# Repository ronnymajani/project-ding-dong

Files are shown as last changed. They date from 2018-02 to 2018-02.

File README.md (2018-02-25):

# Project Ding Dong
An automated doorbell that messages you via a Telegram channel whenever someone rings your doorbell. Powered by the ESP8266
###### [Full Project Description at Hackaday.io](https://hackaday.io/project/61540-project-ding-dong)
------------------------

***The README is not yet complete***

### NOTE:
I omitted a file called `credentials.py` in which I store the TOKEN of my bot and the channel ID that it will push messages to.
So to be able to get the code running don't forget to create this file in the folder `code` and fill it as follows:
``` python
# credentials.py

# This is the generated access token for your telegram bot
TOKEN = ""
# This is the chat id of the channel your bot will push messages to
CHANNEL_ID = ""
# wireless credentials
WIFI_SSID = ""
WIFI_PASS = ""
```

Tools Used:
-------------
- **OpenSCAD** to edit the 3D models for the chassis
- **Telegram** to be able to communicate with the *doorbell*
- **Eagle** to be able to edit the electronic schematics
- **esptool** for flashing the ESP8266
- **mpfshell** for easily transfering files from the computer to the ESP8266

Repository layout:
----------
- **chassis:** this folder contains the OpenSCAD files for the chassis that encompasses the entire system
- **code:** this folder contains the code that will run on the ESP8266
- **schematics:** this folder contains the electronic schematics files that are used to make the PCB board

Third Party Resources and Useful Links:
----------------------
- [Micropython for the ESP8266 Read the Docs page](https://docs.micropython.org/en/latest/esp8266/index.html)
- [urequests.py micropython module](https://github.com/micropython/micropython-lib/blob/master/urequests/urequests.py)
- [Telegram Bots API](https://core.telegram.org/bots/api)
- [mpfshell github page](https://github.com/wendlers/mpfshell)
- [Nice article explaining how to hook up a LiPo battery to the ESP8266](https://randomnerdtutorials.com/esp8266-voltage-regulator-lipo-and-li-ion-batteries/)
- [EagleCAD Library for most/all ESP8266 variants](https://github.com/wvanvlaenderen/ESP8266-Eagle_Library)
- [OpenSCAD Socket Design for the ESP8266-07](https://github.com/makertum/ESP8266-RNS)
- [How to get the your telegram channel's id](https://github.com/GabrielRF/telegram-id#web-channel-id)
- [Eagle CAD library for Microchip components](https://www.element14.com/community/docs/DOC-64255/l/microchip-cad-library-for-cadsoft-eagle-software)
- [Eagle CAD library for basic parts by itead.cc (*like the BC557 PNP BJT*)](https://www.itead.cc/blog/eagle-library-for-basic-parts-series)

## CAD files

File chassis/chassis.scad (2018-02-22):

/**
@title: Project Ding Dong encasing
@author: Ronny Majani
**/
/* Module Definitions */
/*
Creates a block in the dimensions of the chassis
This module uses the globally defined width, height, and depth variables
*/
module chassis_fill(width, height, depth) {
    dimensions = [
        width,
        depth,
        height
    ];
    cube(dimensions);
}

/*
Creates the chassis' hull which is a an outer shell with empty space inside
@param thickness: the thickness of the chassis' inner walls
@param depth: the depth of the inner space
*/
module chassis_hull(width, height, outer_depth, inner_depth, thickness) {
    offset_fix = 0.1;
    inner_dimensions = [
        width - thickness*2,
        inner_depth + offset_fix,
        height - thickness*2
    ];
    difference() {
        chassis_fill(width, height, outer_depth);
        translate([thickness, -offset_fix, thickness]) {
            resize(inner_dimensions) chassis_fill();
        }
    }
}



/* Generate Chassis */
chassis_outer_width = 30;
chassis_outer_height = 48;
chassis_outer_depth = 23;
chassis_inner_depth = 20;
chassis_thickness = 2;
chassis_hull(chassis_outer_width,
            chassis_outer_height,
            chassis_outer_depth,
            chassis_inner_depth,
            chassis_thickness);

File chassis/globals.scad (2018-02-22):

// units are in millimeters
chassis_outer_width = 30;
chassis_outer_height = 48;

chassis_outer_depth = 23;
chassis_inner_depth = 20;

chassis_thickness = 3;

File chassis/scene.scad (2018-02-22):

include <globals.scad>
use <chassis.scad>
use <ESP8266-07-RNS-v7.scad>

%translate([1.5, chassis_inner_depth-9, 10]) rotate([90, 0, 0]) {
    socket();
}
/** Main Scene **/
chassis_hull(chassis_outer_width,
            chassis_outer_height,
            chassis_outer_depth,
            chassis_inner_depth,
            chassis_thickness);;




/** Support Objects **/
/*
Used only as a guide to show how the chassis will be mounted
*/
module mount_grips() {
    width = 5;
    height = 11;
    inner_depth = chassis_outer_depth;
    top_thickness = 2;
    depth = inner_depth + top_thickness;
    side_thickness = 3;
    inner_width = width - side_thickness;

    mirror()translate([-inner_width, -top_thickness, 0]) {
        difference() {
            cube([width, depth, height]);  // outer cube
            translate([-0.2, top_thickness
    , -0.2]) {  // inner cube (cut out)
                cube([inner_width + 0.2, inner_depth+0.2, height + 0.4]);
            }
        }
    }
}

%translate([0, 0, 21]) {
    mount_grips();   

    mirror() translate([-chassis_outer_width, 0, 0]){
        mount_grips();
    }
}

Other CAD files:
chassis/ESP8266-07-RNS-v7.scad

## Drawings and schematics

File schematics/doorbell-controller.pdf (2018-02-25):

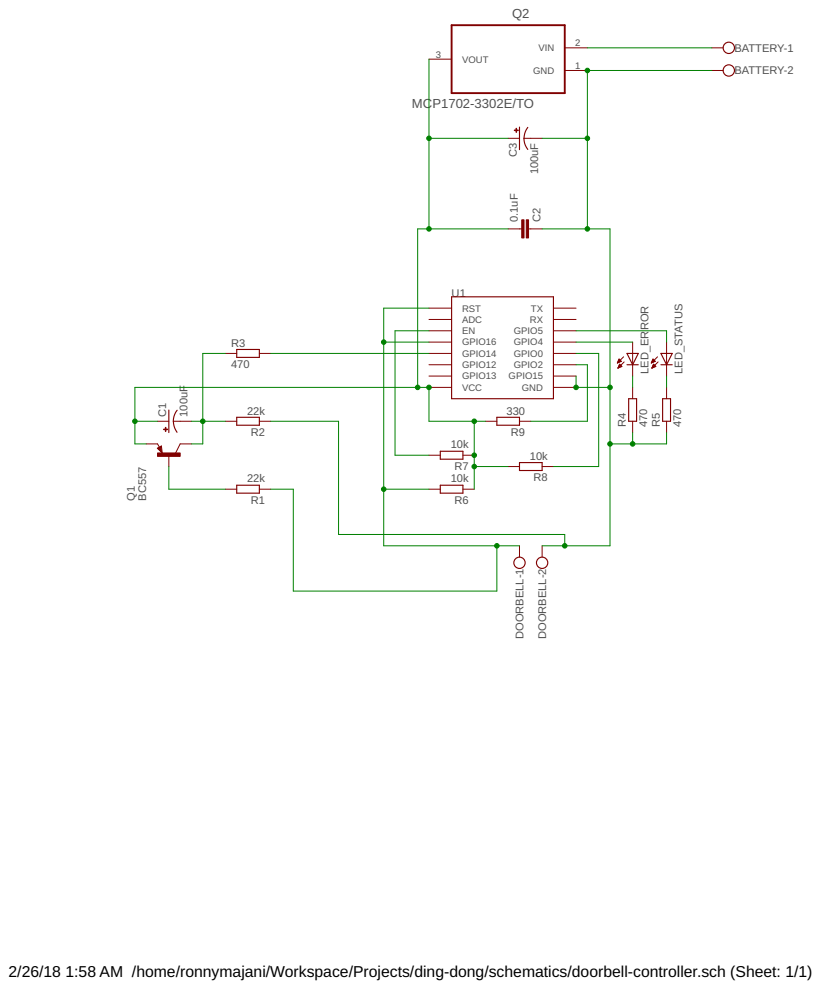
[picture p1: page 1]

2/26/18 1:58 AM /home/ronnymajani/Workspace/Projects/ding-dong/schematics/doorbell-controller.sch (Sheet: 1/1)

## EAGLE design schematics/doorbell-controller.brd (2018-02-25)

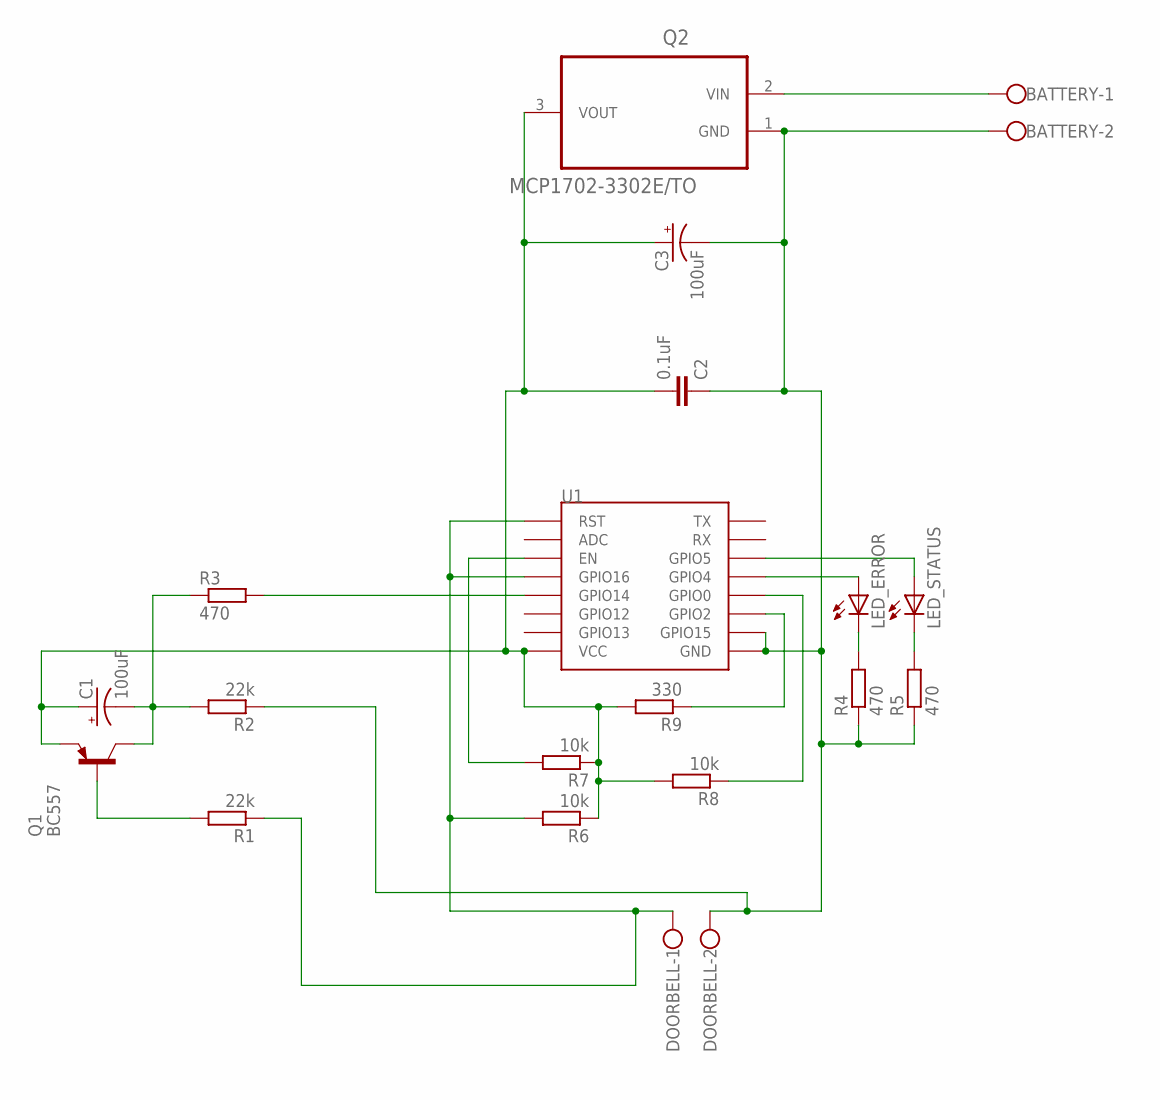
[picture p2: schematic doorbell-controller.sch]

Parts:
BATTERY: W237-102
C1, C3: 100uF; E2,5-6E
C2: 0.1uF; C025-025X050
DOORBELL: W237-102
LED_ERROR: LED5MM
LED_STATUS: LED5MM
Q1: BC557; TO92
Q2: MCP1702-3302E/TO; TO127P254X533-3
R1, R2: 22k; 0204/7
R3, R4, R5: 470; 0204/7
R6, R7, R8: 10k; 0204/7
R9: 330; 0204/7
U1: ESP12-TR

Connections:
BATT_VIN: BATTERY.1, Q2.2 (VIN)
GND: BATTERY.2, C2.1, C3.-, DOORBELL.2, Q2.1 (GND), R2.1, R4.1, R5.1, U1.GND, U1.GPIO15
unnamed: LED_STATUS.A, U1.GPIO5
unnamed: Q1.2 (B), R1.2
unnamed: R3.2, U1.GPIO14
unnamed: LED_ERROR.A, U1.GPIO4
unnamed: C1.-, Q1.3 (C), R2.2, R3.1
unnamed: LED_ERROR.K (C), R4.2
unnamed: LED_STATUS.K (C), R5.2
unnamed: R9.1, U1.GPIO2
unnamed: R7.2, U1.EN
unnamed: R8.1, U1.GPIO0
RST: DOORBELL.1, R1.1, R6.2, U1.GPIO16, U1.RST
VCC: C1.+, C2.2, C3.+, Q1.1 (E), Q2.3 (VOUT), R6.1, R7.1, R8.2, R9.2, U1.VCC

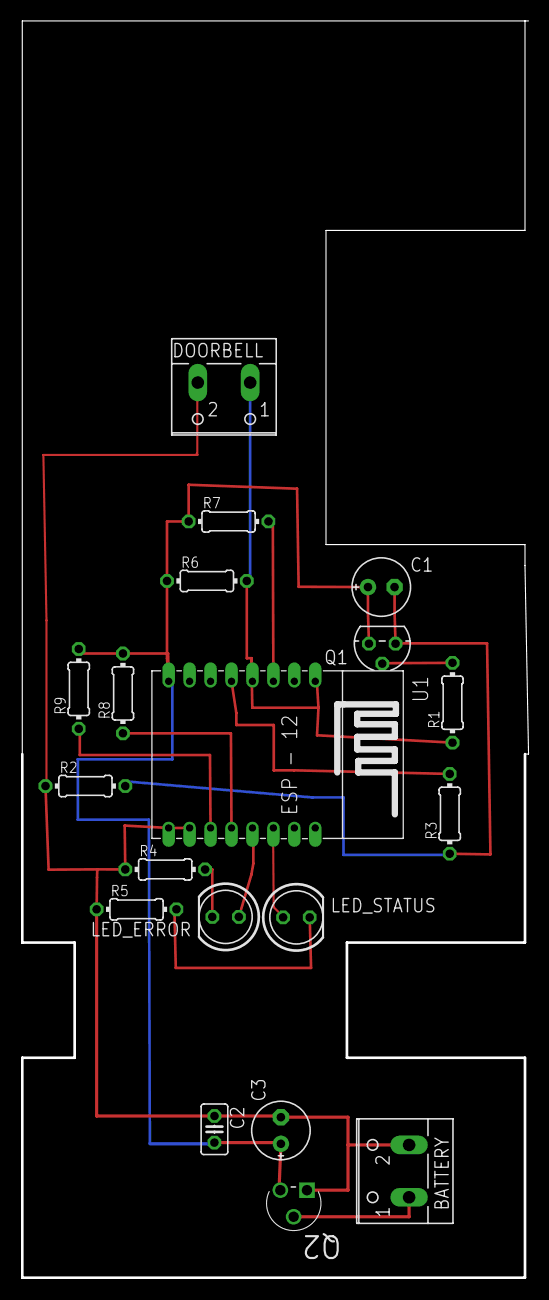
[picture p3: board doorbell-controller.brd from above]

Board: 2 copper layers, 48.3 x 120.0 mm, 19 parts (0 on the bottom side), 14 nets.

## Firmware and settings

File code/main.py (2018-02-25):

# TODO: implement battery status check

import time
import machine
import constants
import credentials
from helpers import *
from networking import NetworkManager


def test():
    from machine import Pin
    x = Pin(14, Pin.IN)
    v = x.value()
    while True:
        print("X:%d, V:%d"%(x.value(), v))
        time.sleep(1)



def setup():
    status_led_off()
    error_led_off()
    # connect to wifi
    if not NetworkManager.connect(credentials.WIFI_SSID, credentials.WIFI_PASS, timeout=constants.WIFI_TIMEOUT):
        ERROR_MODE()

def main():
    status_led_on()
    print("Sending message...")
    send_telegram_knock_message()
    status_led_off()
    # TODO: uncomment
    # enter_deepsleep()


# Run main function
if __name__ == "__main__":
    # test()
    setup()
    main()

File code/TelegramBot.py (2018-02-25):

import requests
try:  # CPython
    import json
except ImportError:  # Micropython
    import ujson as json

class TelegramBot(object):
    def __init__(self, token):
        self.token = token
        self.url = "https://api.telegram.org/bot%s" % self.token

    def _build_url(self, method_name):
        return self.url + "/%s" % method_name

    def _send_request(self, method_name, params):
        url = self._build_url(method_name)
        response = requests.get(url, json=params)
        success = response.json()['ok']
        if success:
            print("Successfully sent message")
        else:
            print("[error] Failed to send message")
        response.close()
        return success

    def sendMessage(self, chatid, text):
        # url += "?chat_id=%s&text=%s" % (chatid, 'test')
        params = {
            'chat_id': chatid,
            'text': text
        }
        return self._send_request('sendMessage', params)

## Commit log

2018-02-22 Began OpenSCAD design of chassis
    [chassis.scad]
2018-02-22 Extracted Globals to separate file
    [globals.scad]
2018-02-22 Created a Scene file; Made chassis modular
    [chassis.scad, scene.scad]
2018-02-22 Added ESP8266 Mount (found it on github)
    [ESP8266-07-RNS-v7.scad, scene.scad]
2018-02-22 Created Eagle Project for schematics; Modified ESP8266 Library
    I had to modify the ESP8266 library, because I have a modified ESP-12 chip that has the GPIO5 and GPIO4 pins swaped
2018-02-22 Renamed folder to 'schematics'
2018-02-22 Created Schematics file; Updated Readme
    [doorbell-controller.sch]
2018-02-25 Check if the device woke up due to an interrupt or due to RTC timeout
2018-02-25 Added interrupt extender to schematics
    [doorbell-controller.brd, doorbell-controller.sch]
2018-02-25 Added LEDs to schematics; Replaces button with Clamp
    [doorbell-controller.brd, doorbell-controller.sch]
2018-02-25 Hooked up RST to GPIO16
    [doorbell-controller.brd, doorbell-controller.sch]
2018-02-25 Uses helpers.py; Uses LEDs; Handles multiple "knocks"
2018-02-25 Removed redundant "knock again" function
    Since the doorbell is hardwired to the RST pin, there's no way to prevent the device from resetting when the doorbell is knocked therefore, it's redundant to make a loop and check for another press of the doorbell (which would cause the device to reset)
    [helpers.py, main.py]
2018-02-25 Added check for Telegram send message failure
    [TelegramBot.py, helpers.py]
2018-02-25 Updated Schematics to fit wall mount dimensions
    [doorbell-controller.brd, doorbell-controller.sch]
2018-02-25 Added voltage regulator to schematics
    [doorbell-controller.brd, doorbell-controller.sch]
2018-02-25 Exported pdf of schematics
